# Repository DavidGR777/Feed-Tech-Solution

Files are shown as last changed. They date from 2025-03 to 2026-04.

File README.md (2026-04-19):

# Feed-Tech-Solution
IoT System for Feeding and Growth Monitoring in Cattle.
Project developed as part of the emphasis "IoT Fundamentals and Applications."
The IoT system included the next activities and tasks:

- Implementation of an IoT system using a Raspberry Pi 3 microprocessor.

- Application of RFID, flow, and load sensors.

- Implementation of servomotor actuador, LED RGB and an alert system.

- Delevopment of a project web page using database MySQL and back-end for PHP

- Cloud computing implementation and data performance in a Dashboard using Thingsboard

[Project conception doc](docs/project_conception.pdf)

<p align="center">
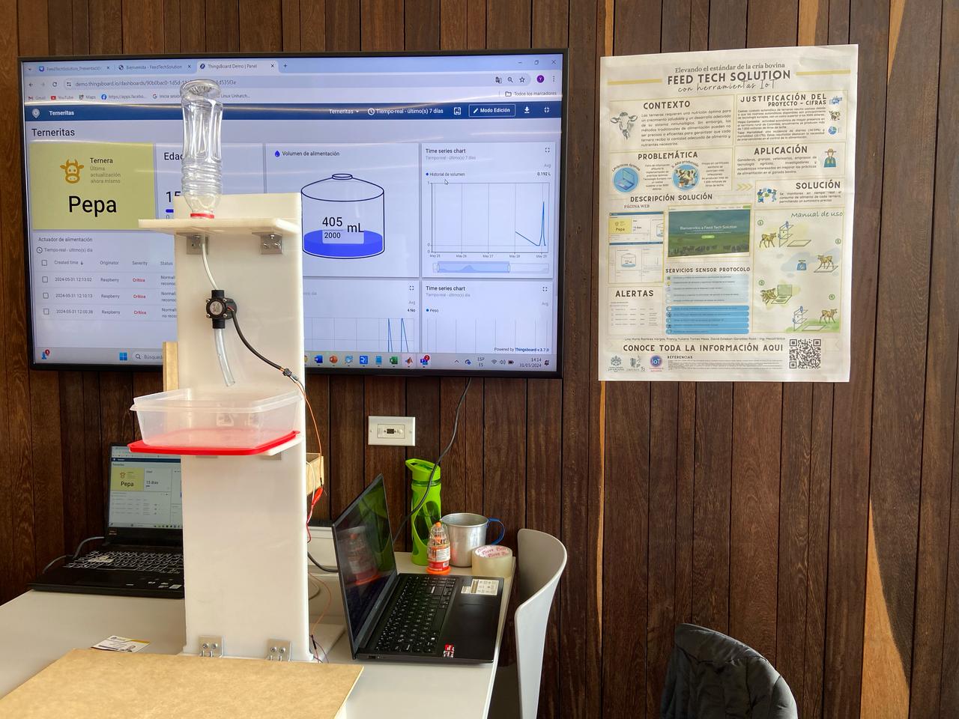
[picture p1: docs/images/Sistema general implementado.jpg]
  
</p>

### Expo-proyectos Javeriana participation certificate  
This project was presented in Expo-proyectos Javeriana and we got the following certificate of participation 
[Certificado](docs/expoproyectos/Certificado_Expoproyectos.pdf)

### 🌐 Active web page  
You can explore the  active project web page here:
🔗 [Feed-Tech-Solution Web](http://feedtechsolution.infinityfreeapp.com/). The Free Web Hosting of the web page is infinityfree. It is able to support back-end with PHP y MySQL

## Project Members

- Lina Ramírez
- Yuliana Torres
- David González

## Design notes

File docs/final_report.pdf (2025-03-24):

PONTIFICIA UNIVERSIDAD JAVERIANA
FACULTAD DE INGENIERIA - DEPARTAMENTO DE ELECTRONICA INTERNET DE LAS COSAS

Entrega Fase 3 – Feed Tech Solution.

Ramírez Vargas, Lina María#1 González Rozo, David Esteban#2 Torres Mesa, Francy Yuliana#3

Ingeniería mecatrónica, Pontificia Universidad Javeriana Bogotá, Colombia

1

lina.ramirezv@javeriana.edu.co 2desteban.gonzalezr@javeriana.edu.co 3 torresmfrancy@javeriana.edu.co

Se realizaron ajustes iniciales en el código para permitir la transmisión de datos a ThingsBoard. El primer cambio se centró en la conexión, que se dividió en dos partes: el host y el token del dispositivo. Inicialmente, el dominio era 10.195.28.12; sin embargo, se observó que este dominio solo era funcional con el internet de la universidad, lo que impedía la conexión con la Raspberry. Por lo tanto, se creó una nueva cuenta en ThingsBoard, a partir de la cual se desarrolló toda la interfaz de usuario.

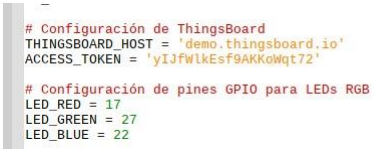
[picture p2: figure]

Además, se incorporó un LED RGB para indicar cuando el sensor RFID RC522 identificaba un tag. Cuando la ternera estaba registrada en la base de datos, el LED mostraba luz verde; en caso contrario, se encendía en rojo. Por lo que no se está utilizando el canal azul del Led.

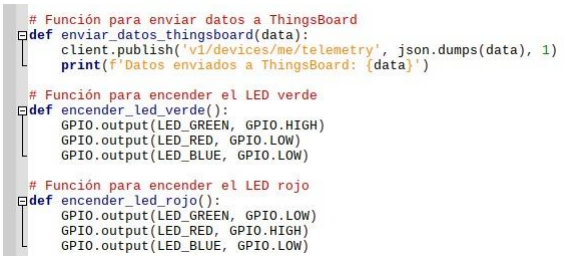
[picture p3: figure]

El actuador utilizado fue un servomotor, encargado de abrir o detener el flujo de alimento para las terneras. Su funcionamiento se divide en dos fases: primero, cuando un tag se acerca al sensor de identificación, el servomotor se activa y gira su palanca 180°, permitiendo el flujo de leche hacia la taza de las terneras a través de una manguera. Dado que la cantidad de alimento está estipulada según la edad de las terneras, una vez que se alcanza el volumen esperado, el servomotor se activa nuevamente, regresando a su posición inicial para detener el flujo.

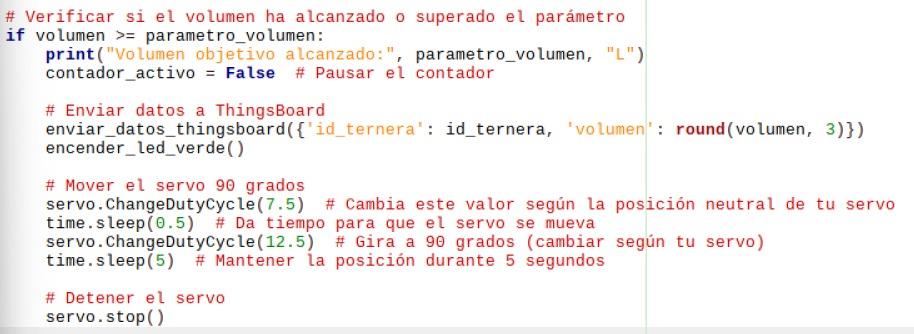
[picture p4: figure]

Para implementar las alertas en el dashboard, se crearon diagramas de flujo en ThingsBoard. En este caso, se configuró una alerta para el sensor de identificación. Esta alerta se activa cuando una ternera se registra más de dos veces al día.

El proceso comenzó con el diseño de un diagrama de flujo que define los criterios y las condiciones necesarias para generar la alerta. Si el sistema detecta que una ternera ha sido registrada más de dos veces en un día, se envía una notificación al panel de control.

Esta alerta es indispensable para asegurar que las terneras no reciban más alimento del que está establecido, manteniendo un control sobre su alimentación.

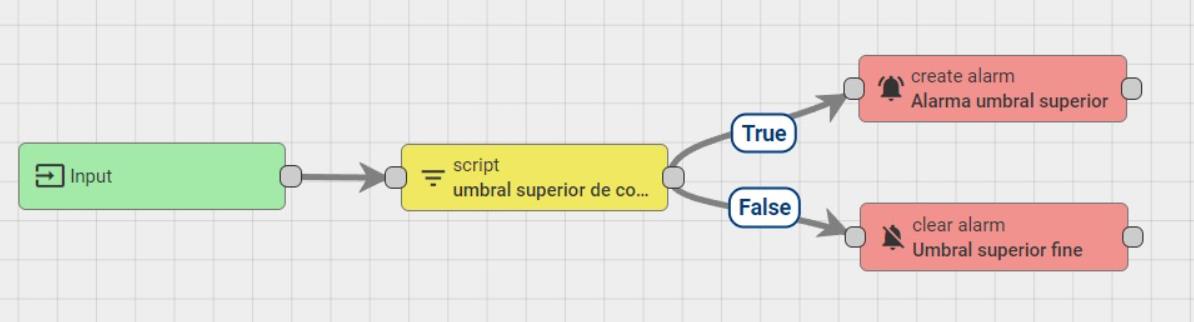
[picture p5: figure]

Otro cambio que se realizó, siguiendo la recomendación del profesor, fue la modificación del sistema de registro por correo electrónico. Ahora es posible registrarse utilizando cualquier dominio, como 'gmail.com', 'javeriana.edu.co', entre otros, lo cual era necesario, ya que anteriormente, el sistema de registro estaba restringido a ‘gmail.com’, lo cual limitaba la accesibilidad para algunos usuarios.

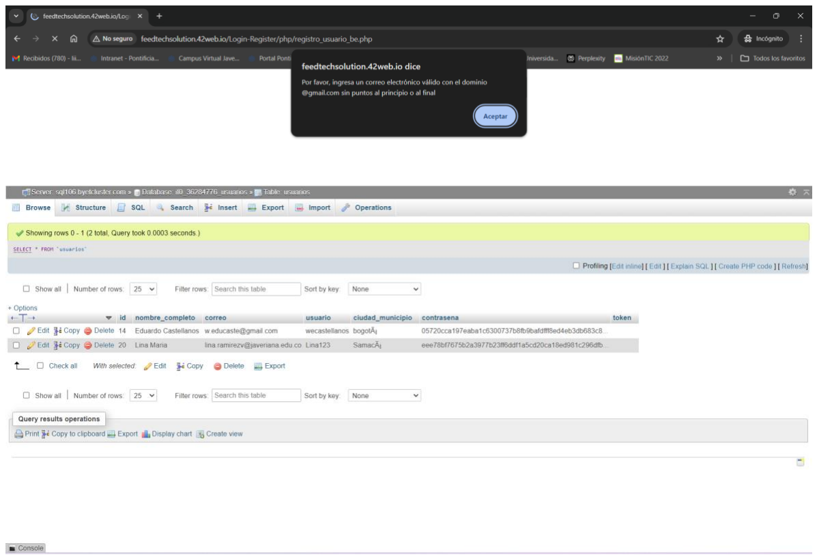
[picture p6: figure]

Además, se intentó implementar la función de 'Olvidó su contraseña'. Sin embargo, a pesar de numerosos intentos, no fue posible debido a las limitaciones del hosting gratuito, que restringe ciertas opciones, incluida la recuperación de contraseñas.

Se intentó resolver este problema utilizando el protocolo de comunicación SMTP para enviar correos electrónicos de recuperación de contraseña. Sin embargo, las restricciones del hosting gratuito impidieron completar esta configuración. Por lo tanto, esta funcionalidad no pudo ser implementada en la plataforma actual.

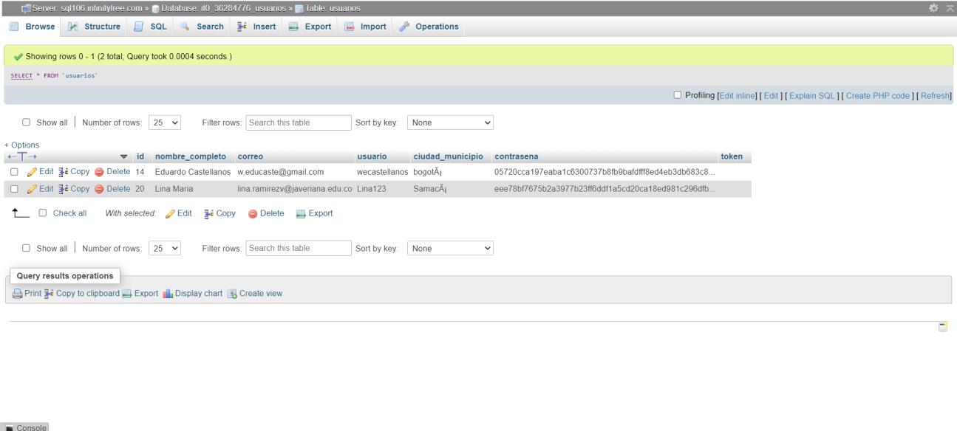
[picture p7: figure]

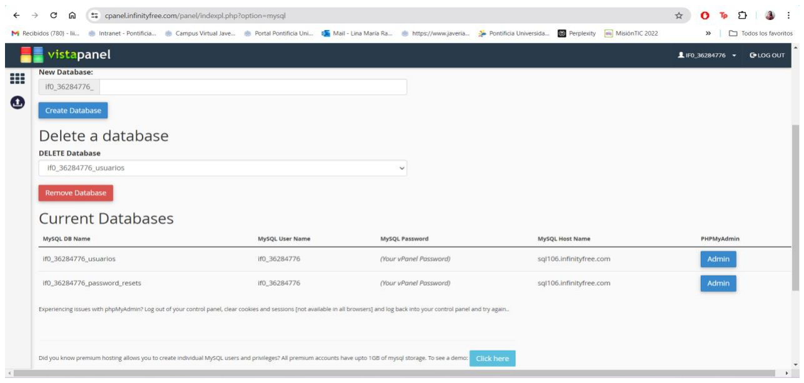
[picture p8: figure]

Para la implementación del dashboard, se conectó el código unificado de los sensores utilizando el dominio y el token del dispositivo, como se mencionó anteriormente. Las primeras pruebas se realizaron con el sensor de identificación, utilizando la información almacenada en la base de datos local de cada tag, que incluía la edad y el ID único de cada ternera.

Posteriormente, se realizó una prueba enviando los datos del sensor de flujo. En este caso, se configuró una alerta para detectar si se recibe más leche de la esperada según la tabla de alimentación disponible en la página web del proyecto. Esta alerta indica un posible fallo en el actuador encargado de detener el flujo de la leche.

Además, se creó un gráfico que muestra el peso inicial de cada ternera y su evolución a lo largo del tiempo. Este gráfico permite monitorear el crecimiento de las terneras y ajustar su alimentación en consecuencia, asegurando un desarrollo saludable y adecuado para cada una.

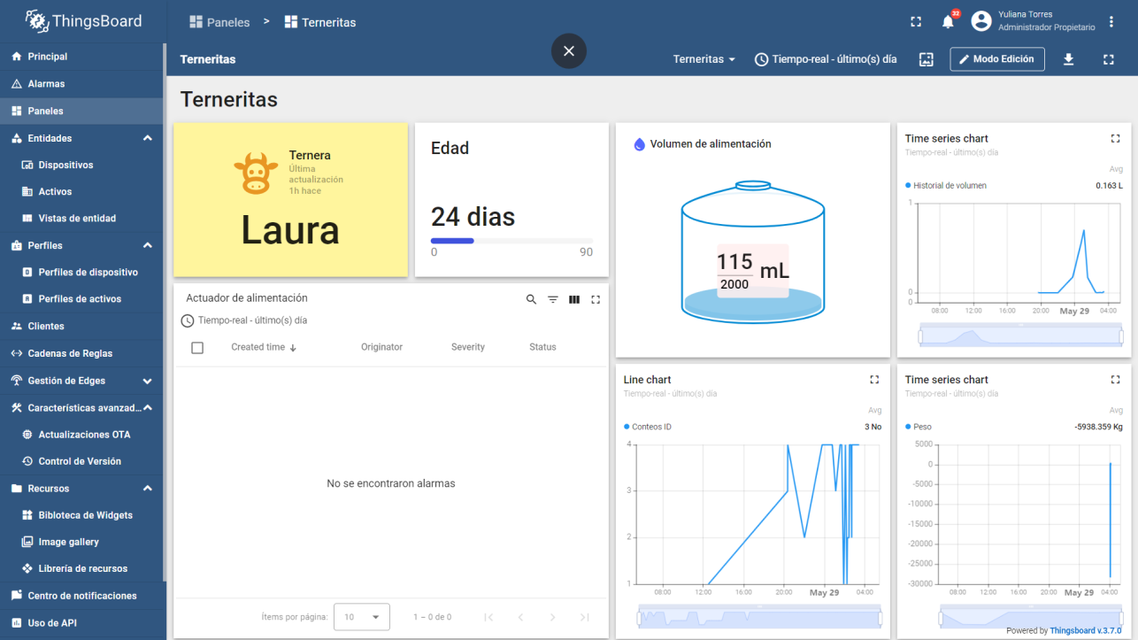
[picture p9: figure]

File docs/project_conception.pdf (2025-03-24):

# Proyecto

# SOLUCIÓN

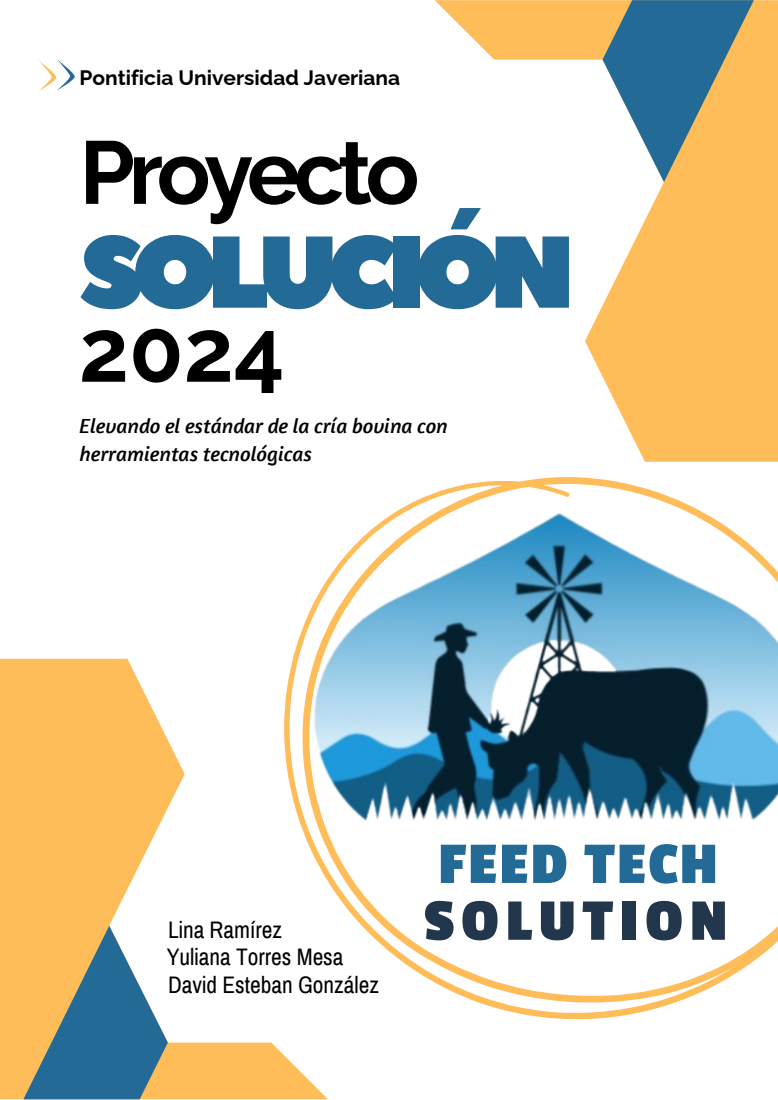
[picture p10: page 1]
FEED TECH SOLUTION

Pontificia Universidad Javeriana

Elevando el estándar de la cría bovina con
herramientas tecnológicas

Lina Ramírez
Yuliana Torres Mesa
David Esteban González

# Área de aplicación

# Descripción del problema

El proyecto Feed Tech Solution tiene como área de aplicación principal la industria ganadera, específicamente en la cría y cuidado
de terneras durante los primeros meses de vida.

Este sistema innovador de alimentación está diseñado para su utilización por ganaderos, productores de leche, granjas, veterinarios, empresas de tecnología agrícola, así como investigadores y académicos interesados en mejorar las prácticas de alimentación y nutrición en el ganado bovino.

## Justificación:

El problema que Feed Tech Solution busca resolver radica en la dificultad que enfrentan los ganaderos para proporcionar una alimentación adecuada y equilibrada a las terneras durante los primeros meses de vida en las fincas ganaderas. Durante este período, las terneras requieren una nutrición óptima para un crecimiento saludable y un desarrollo adecuado de su sistema inmunológico. Sin embargo, los métodos tradicionales de alimentación pueden no ser suficientemente preciso o eficientes para garantizar que cada ternera reciba la cantidad adecuada de alimento y los nutrientes necesarios. Esto puede conducir a problemas de crecimiento deficiente, enfermedades, infecciones que pueden causar la muerte y/o una menor productividad en el ganado a largo plazo. Por lo tanto, el desafío radica en encontrar una solución que permita a los ganaderos monitorear y controlar de manera efectiva la alimentación de las terneras, asegurando así su salud y bienestar desde una etapa temprana.

En Colombia la disponibilidad de información sobre ganadería, especialmente en lo que respecta al crecimiento y desarrollo de las terneras, es limitada, a pesar de la importancia del sector para la economía nacional. Esta falta de información podría dificultar la implementación de prácticas óptimas en la cría de ganado bovino. Además, el cuidado automático de terneras resulta costoso debido a que las nodrizas automáticas disponibles son principalmente de tecnología europea, con un costo superior a los 3000 dólares por unidad. Esta inversión representa un desafío para los ganaderos, especialmente los de pequeña escala o con recursos limitados.

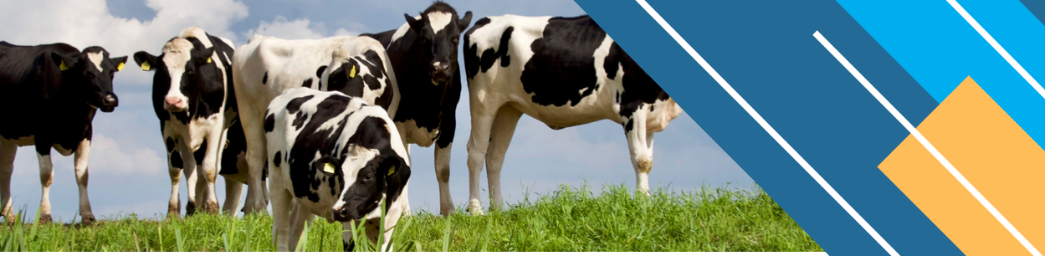
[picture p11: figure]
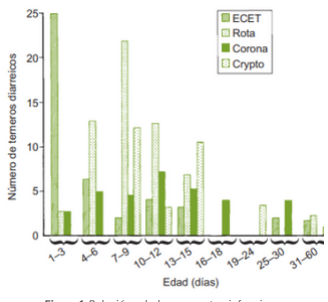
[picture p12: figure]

# Descripción de la solución

## Cifras y estadísticas:

La ganadería es la actividad económica de mayor presencia en el territorio rural de Colombia, anualmente se producen más de 7.000 millones de litros de leche, siendo la ganadería 3 veces más que el sector cafetero y 5,2 veces más que el sector bananero. [1]

En cuanto a la alimentación, según un estudio en terneros
Holstein de 2 a 65 días, reveló una alta incidencia de
diarrea (48.59%) y mortalidad (20.17%). Estos resultados
destacan la necesidad de intervenciones en el control de la alimentación para reducir estos problemas. [2]

En otro estudio realizado en una de las fincas ganaderas de Antioquia sin un plan sanitario certificado, se observa que en las primeras semanas se es más susceptible a contraer infecciones como se ve en la gráfica. [3]

Figura 1. Relación edad con agentes infecciosos

La solución propuesta para la automatización de la alimentación de terneras en sus primeros días de vida integra tecnología de Internet de las Cosas (IoT) para ofrecer un nuevo enfoque.
A través de sensores y dispositivos conectados, se monitorea en tiempo real el consumo de alimento de cada ternera, permitiendo un suministro preciso y personalizado según las necesidades individuales de cada animal. Los datos recopilados son analizados mediante algoritmos programados, lo que permite ajustar automáticamente la cantidad y frecuencia de alimentación para optimizar el crecimiento y la salud de las terneras.

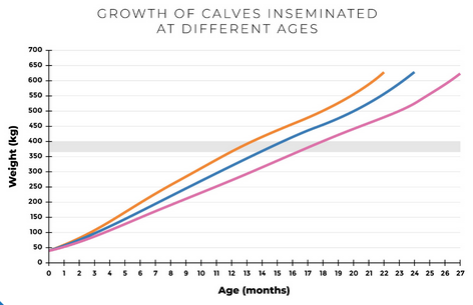
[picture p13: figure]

Además, la plataforma IoT proporciona alertas en tiempo real sobre cualquier anomalía o problema en el proceso de alimentación, permitiendo una respuesta rápida y eficaz por parte del personal encargado.

Figura 2. Crecimiento esperado para terneros.

En el siguiente diagrama se proporciona uan representación de los diferentes componentes y como interactúan entre sí.

## Diagrama de bloques:

El fenómeno del crecimiento compensatorio no se aplica luego, así que los primeros seis meses de vida son importantes. Un crecimiento de unos 800g/día es óptimo para la ternera (ver figura 2). Las terneras mas pesadas a los 6 meses (>200kg) son las que presentan mejores resultados de fertilidad, longevidad y producción de leche. [4]

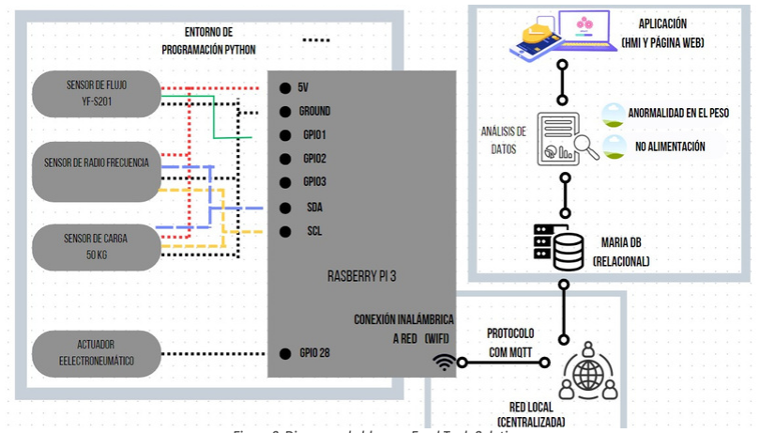
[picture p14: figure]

Este diagrama ofrece una visión general del funcionamiento del sistema, proporcionando una guía visual para comprender su operación de manera intuitiva.

## Diagrama de alto nivel:

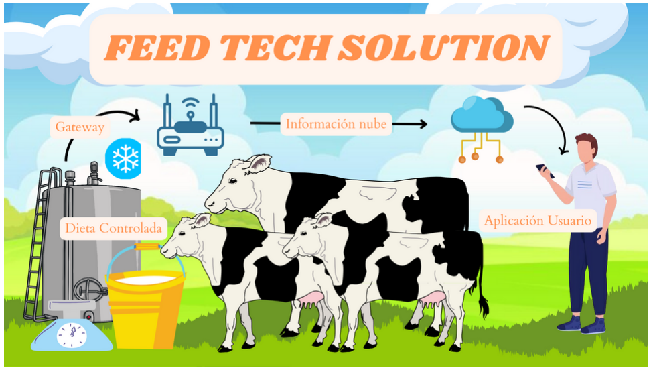
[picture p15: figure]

Figura 4. Diagrama de alto nivel Feed Tech Solution.

Figura 3. Diagrama de bloques Feed Tech Solution.

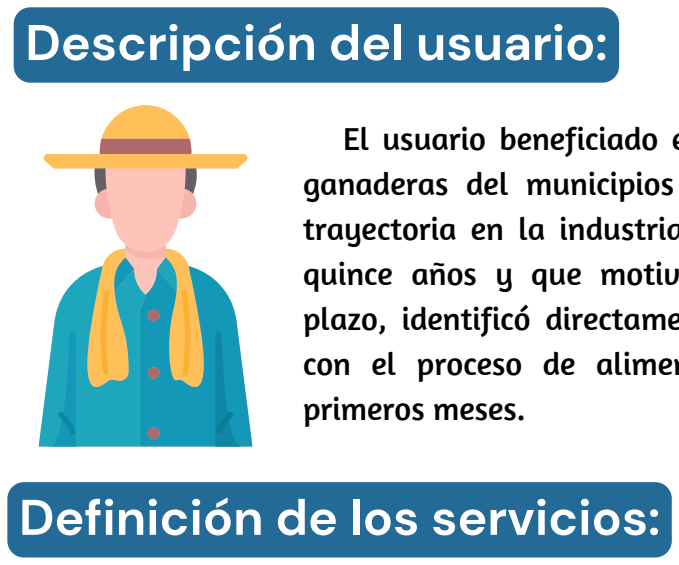
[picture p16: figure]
primeros meses.; Descripción del usuario:; Definición de los servicios:

El usuario beneficiado es el dueño de una de las fincas ganaderas del municipios de Samacá - Boyacá, con una trayectoria en la industria ganadera de aproximadamente quince años y que motivado por el crecimiento a largo plazo, identificó directamente la problemática relacionada con el proceso de alimentación de sus terneras en los

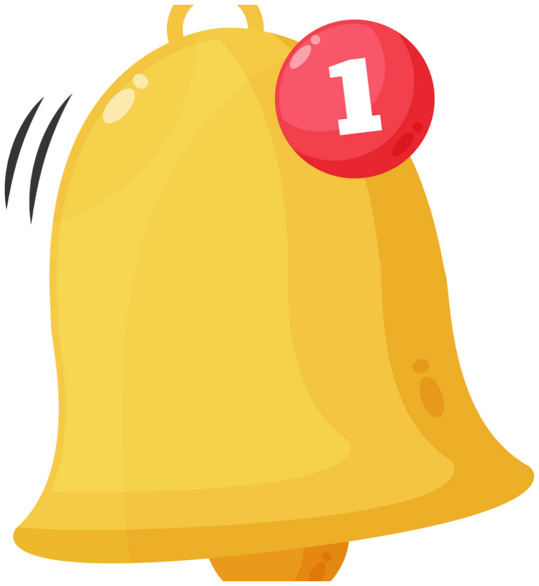
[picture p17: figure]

Dentro de la configuración de los sensores es necesario tener en cuenta y establecer un parámetro generalizado de la cantidad de alimento para cada una de las terneras. En la figura 4 se muestra la cantidad según el peso del animal. Además, se considera una temperatura que en lo posible debe ser la misma siempre y a la misma hora.
La higiene es tambien fundamental por lo que este al ser un sistema cerrado minimiza la intervención externa y por tanto la posibilidad de infecciones.

## Descripciones generales:

La implementación de tecnología permite el control y monitoreo eficiente de las nodrizas, proporcionando la cantidad precisa y control de las terneras, replicando el cuidado e higiene para evitar las infecciones. Los servicios son: 1.Implementación del sistema: configuración de los sensores y actuadores 2.Desarrollo de software: Plataforma personalizada con interfaz de usuario

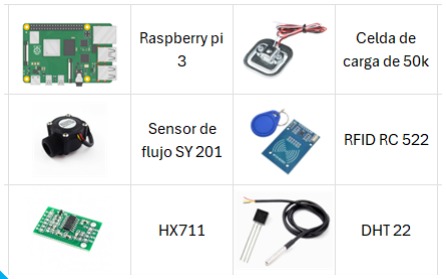
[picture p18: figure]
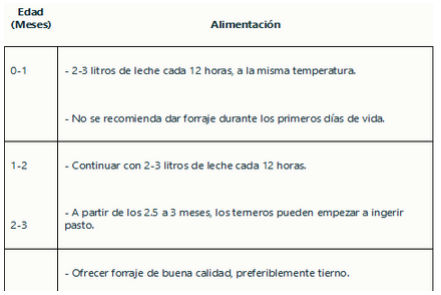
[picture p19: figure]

Figura 3. Implementos usados en el proyecto. | Figura 4. Alimentación de las terneras según la edad.
- Raspberry pi 3: microcontrolador base - Sensor sy 201: flujo de leche para cada ternera - Celda de carga de 50k: validar el peso de la ternera a diario. -DSB 18b20: sensor de monitoreo de temperatura de la leche - RFID RC 522: sensor de identificación
- HX 711: es el módulo de conversor analógico - digital para la celda de carga.

En la interfaz gráfica de usuario se espera que al ser de fácil manejo, los datos y el uso para el ganadero sea casi intuitivo. En primer lugar se presenta información de caracterización de la ternera, con datos adicionales que se deseen adicionar, seguido de esto, la edad y el número de identificación. La gráfica de crecimiento muestra si se está dando de manera correcta según los parámetros ya comentados y un botón de alerta por si no funciona bien el sistema. Lo siguiente son las gráficas de peso, una personal y la otra respecto a un promedio y de igual manera la cantidad de alimento suministrado. La información de siguiente fase corresponde al porcentaje de avance durante los tres meses, una vez cumplida esta edad, sale de este proceso de alimentación, pues ahora debe comer concentrado.

# Interfaz gráfica de usuario

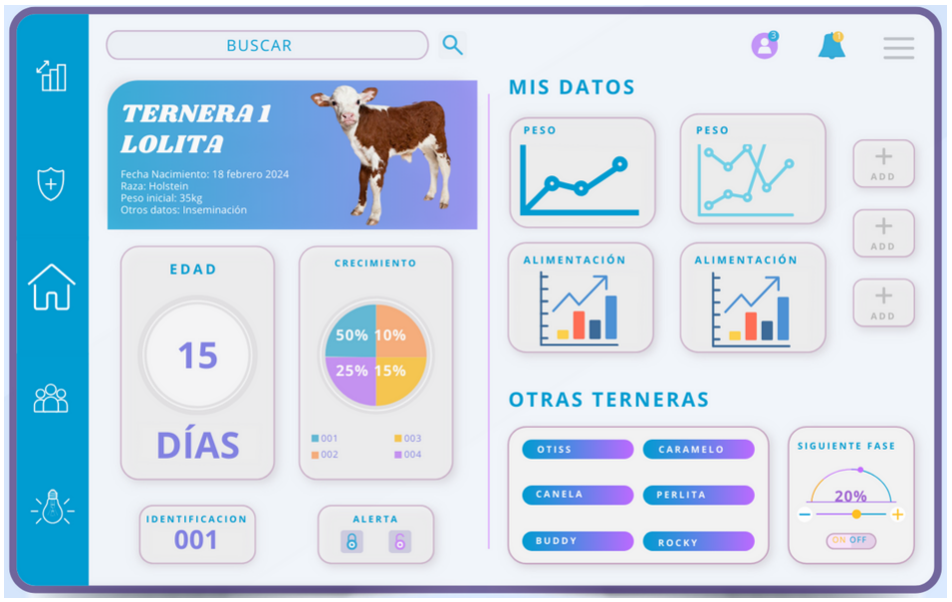
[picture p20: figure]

Figura 5. Interfaz gráfica de usuario.

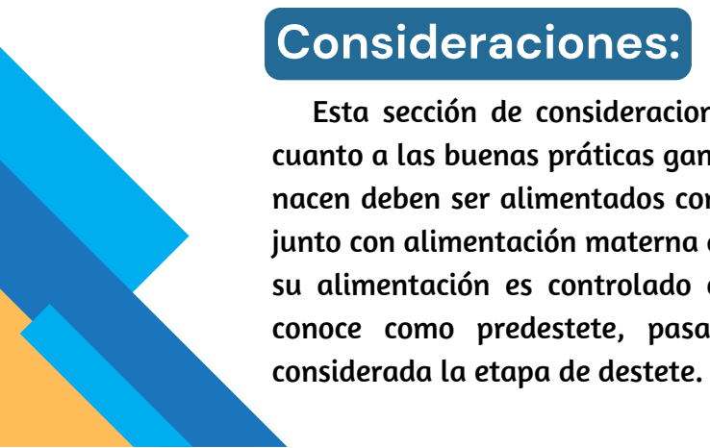
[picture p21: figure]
considerada la etapa de destete.; Consideraciones:

Esta sección de consideraciones tiene en cuenta otros datos adicionales en cuanto a las buenas práticas ganaderas y de cuidado de los terneros. Tan pronto nacen deben ser alimentados con calostros y dentro de estas primeras 24 horas junto con alimentación materna debe adquirir 10 kilos de peso. A partir del día 2, su alimentación es controlado con Feed Tech Solution y a esta estapa se le conoce como predestete, pasados tres meses sale de este proceso y es

# Antecedentes

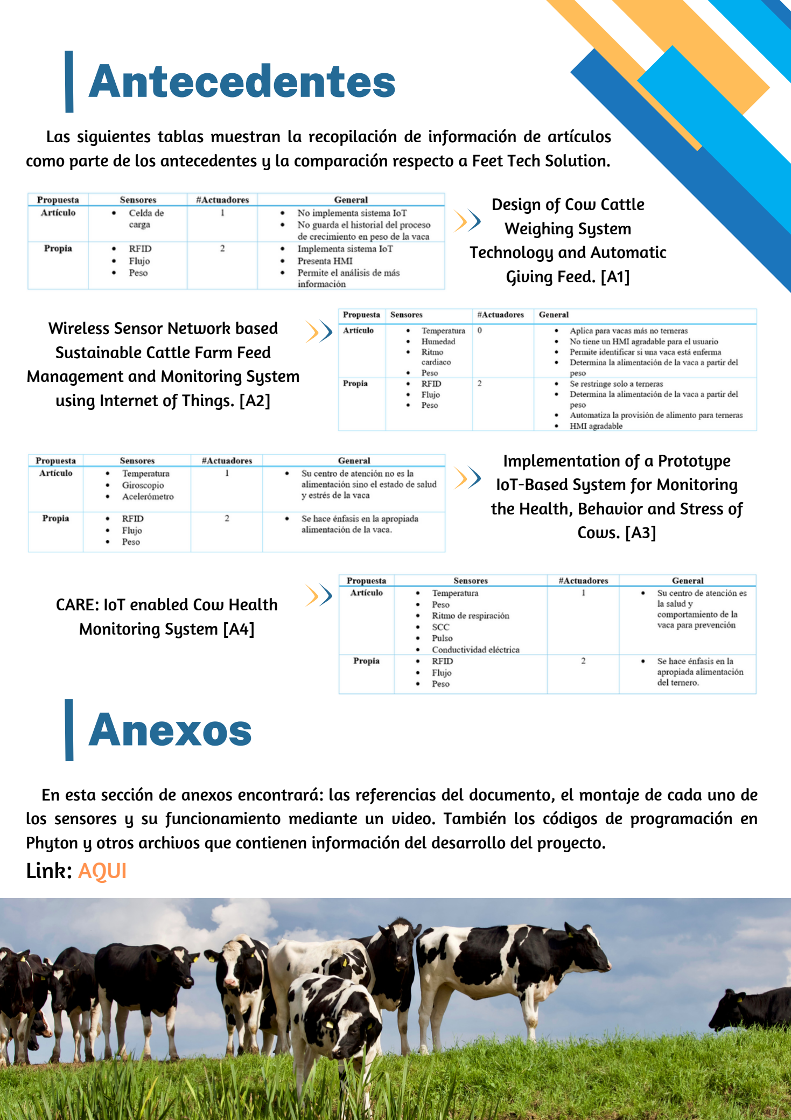
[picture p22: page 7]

Las siguientes tablas muestran la recopilación de información de artículos como parte de los antecedentes y la comparación respecto a Feet Tech Solution.

# Anexos

En esta sección de anexos encontrará: las referencias del documento, el montaje de cada uno de los sensores y su funcionamiento mediante un video. También los códigos de programación en Phyton y otros archivos que contienen información del desarrollo del proyecto.
Link: AQUI (https://livejaverianaedu-my.sharepoint.com/:f:/g/personal/lina_ramirezv_javeriana_edu_co/EnmLIeDjfP5OvYbf9VVIlEoBRGlZDpHc1Rl4A16tMxb4Pg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)

Design of Cow Cattle
Weighing System
Technology and Automatic
Giving Feed. [A1]

Wireless Sensor Network based Sustainable Cattle Farm Feed Management and Monitoring System using Internet of Things. [A2]

Implementation of a Prototype IoT-Based System for Monitoring the Health, Behavior and Stress of Cows. [A3]

CARE: IoT enabled Cow Health Monitoring System [A4]

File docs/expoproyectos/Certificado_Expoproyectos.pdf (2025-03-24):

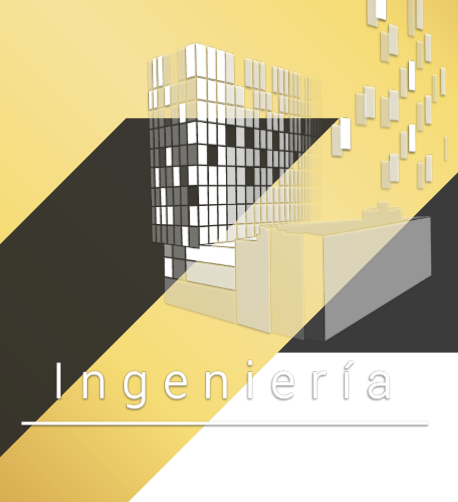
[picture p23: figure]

# Certificado de Participación

EN RECONOCIMIENTO AL PROYECTO Feed Tech Solution

Lina María Ramírez Vargas, Francy Yuliana Torres Mesa, David Esteban González Rozo

POR SU COMPROMISO Y PARTICIPACIÓN EXPO PROYECTOS 2410
PONTIFICIA UNIVERSIDAD JAVERIANA

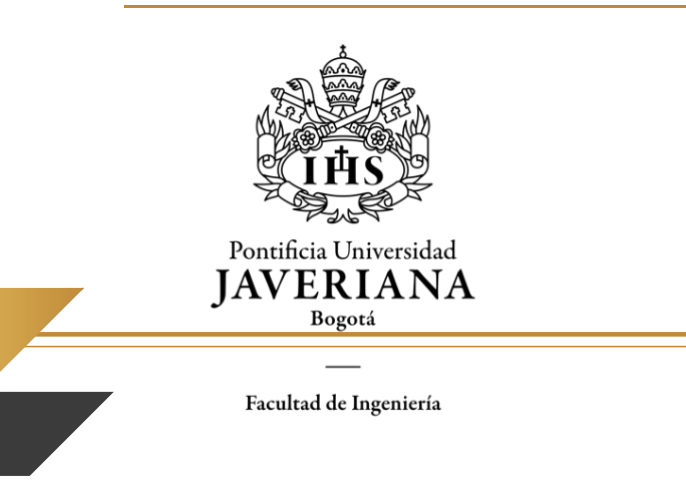
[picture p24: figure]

31 Mayo 2024 | Director de Carrera

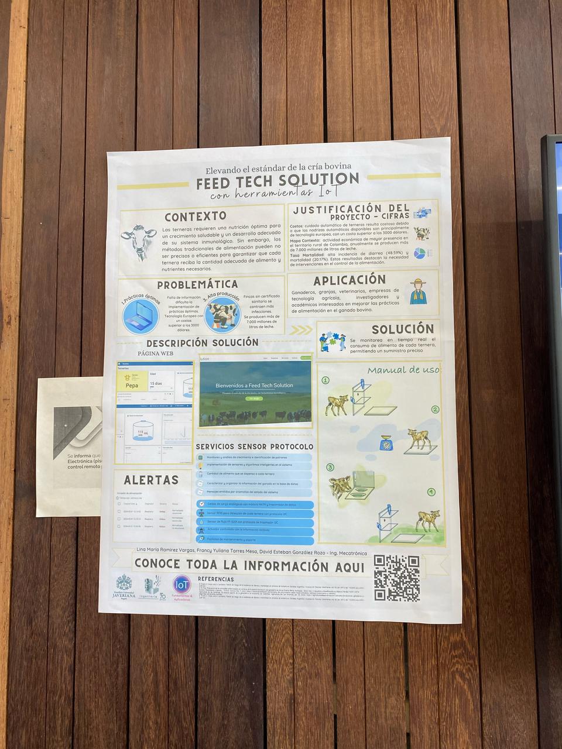
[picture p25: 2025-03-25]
docs/images/poster expo.jpg

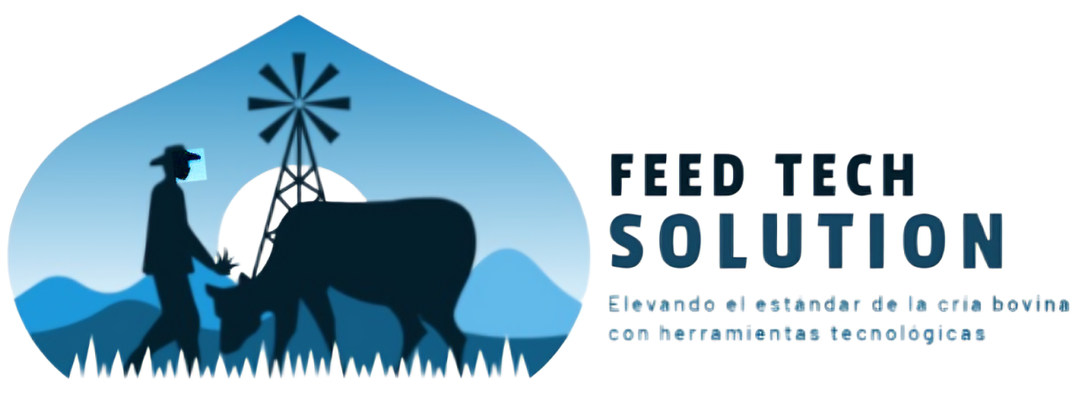
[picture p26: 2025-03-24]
web-page/img/Diseño sin título.png

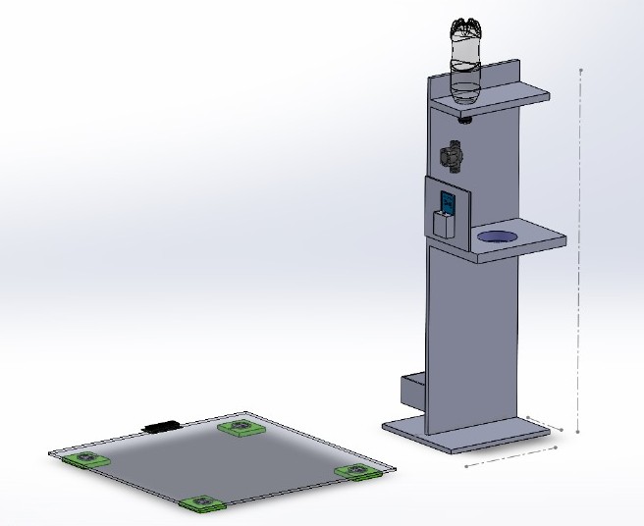
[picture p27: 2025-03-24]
cad-design/Diseño CAD.jpg

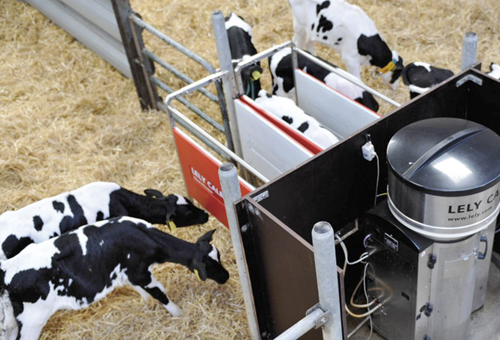
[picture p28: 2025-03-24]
web-page/img/imagen9.jpg

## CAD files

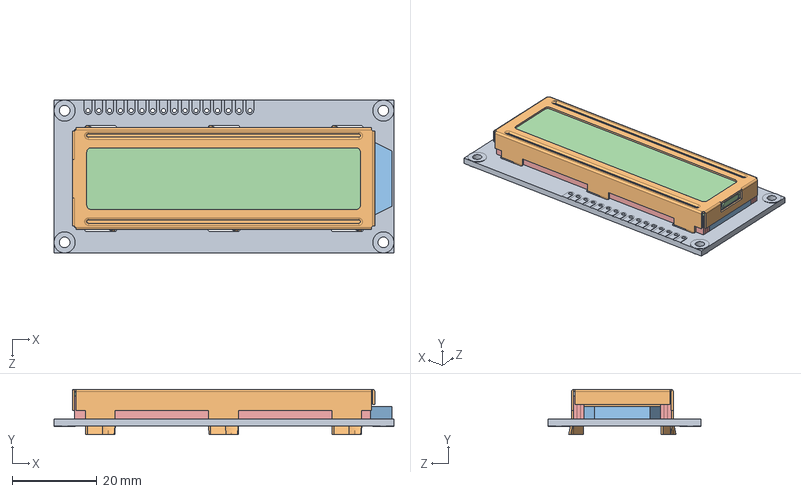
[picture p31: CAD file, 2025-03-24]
cad-design/LCD/DFRobot_1602_LCD.SLDASM
80.0 x 10.6 x 36.0 mm
LCD_PCB
metal_casing
LCDbacklight
LCD
conductors x 2

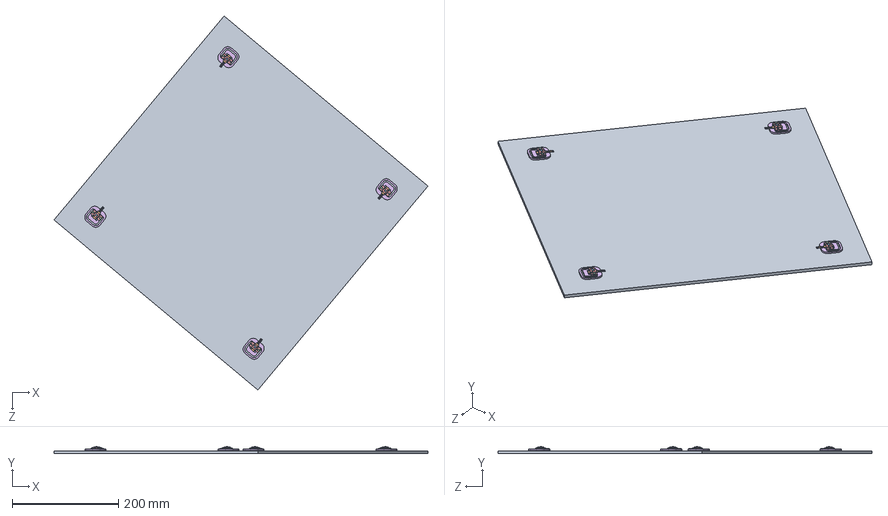
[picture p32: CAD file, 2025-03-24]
cad-design/Celda de carga/Balanza.SLDASM
704.2 x 13.8 x 704.2 mm
BASE, 50 kg Load Cell Resistance Strain Half Bridge Sensor x 4
FLANGED TOP, 50 kg Load Cell Resistance Strain Half Bridge Sensor x 4
SIDE RIVET, 50 kg Load Cell Resistance Strain Half Bridge Sensor x 5
MIDDLE RIVET, 50 kg Load Cell Resistance Strain Half Bridge Sensor x 4
WIRED CONNECTION, 50 kg Load Cell Resistance Strain Half Bridge Sensor x 4
Base sup celda

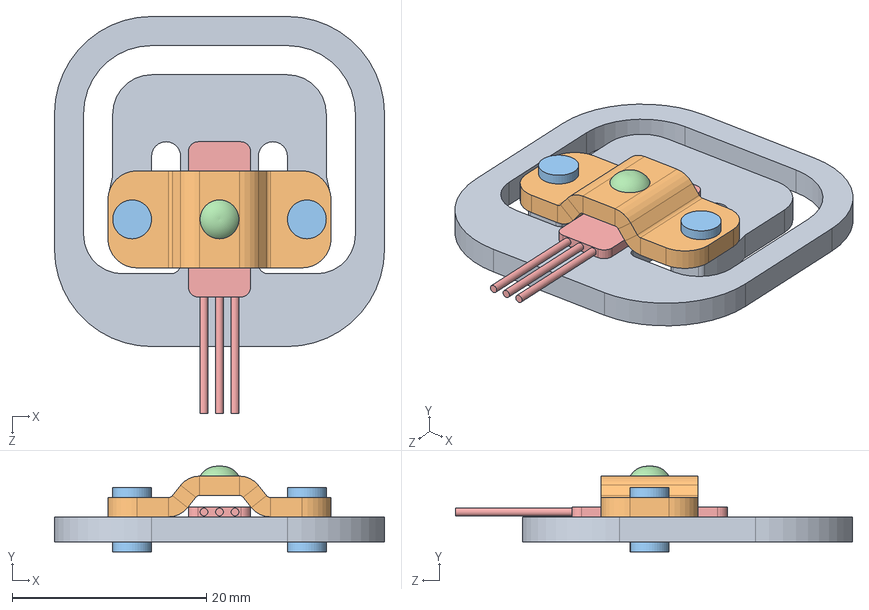
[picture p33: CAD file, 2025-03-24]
cad-design/Celda de carga/50 kg Load Cell Resistance Strain Half Bridge Sensor.SLDASM
34.0 x 8.82 x 40.9 mm
BASE, 50 kg Load Cell Resistance Strain Half Bridge Sensor
FLANGED TOP, 50 kg Load Cell Resistance Strain Half Bridge Sensor
SIDE RIVET, 50 kg Load Cell Resistance Strain Half Bridge Sensor x 2
MIDDLE RIVET, 50 kg Load Cell Resistance Strain Half Bridge Sensor
WIRED CONNECTION, 50 kg Load Cell Resistance Strain Half Bridge Sensor

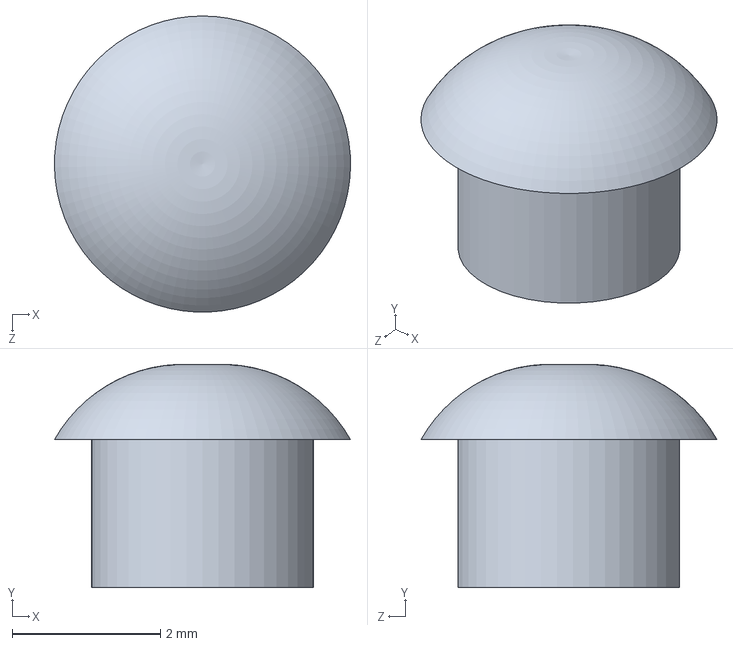
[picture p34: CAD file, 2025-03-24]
cad-design/Celda de carga/MIDDLE RIVET, 50 kg Load Cell Resistance Strain Half Bridge Sensor.SLDPRT
4.00 x 3.02 x 4.00 mm

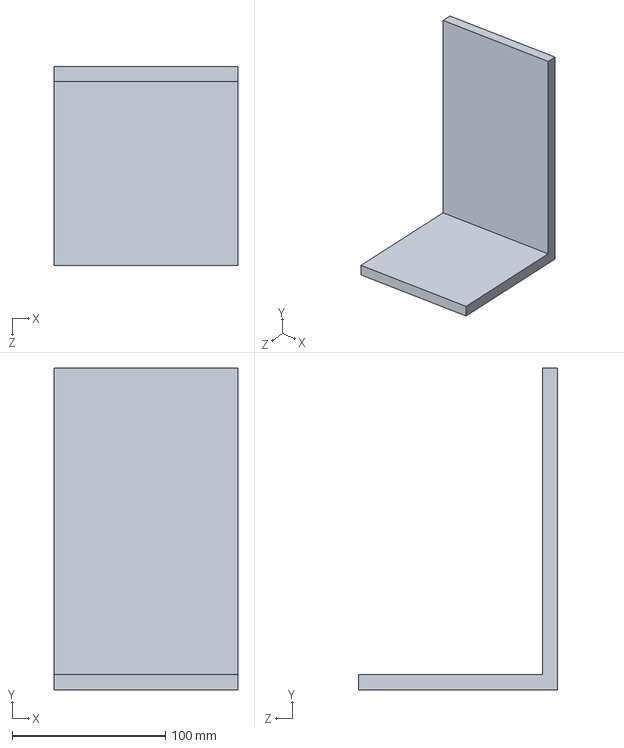
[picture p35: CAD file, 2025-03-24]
cad-design/estructura.SLDPRT
120.0 x 210.0 x 130.0 mm

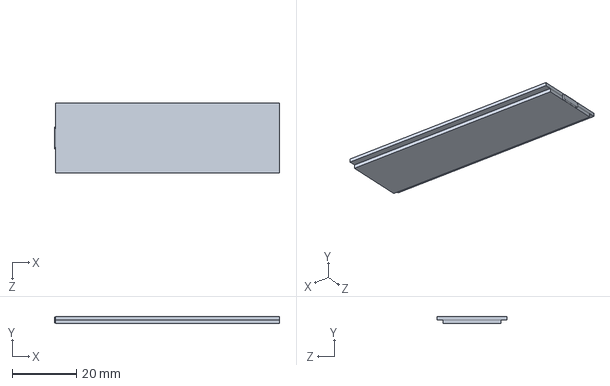
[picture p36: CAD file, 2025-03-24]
cad-design/LCD/LCD.SLDPRT
70.3 x 2.10 x 22.0 mm

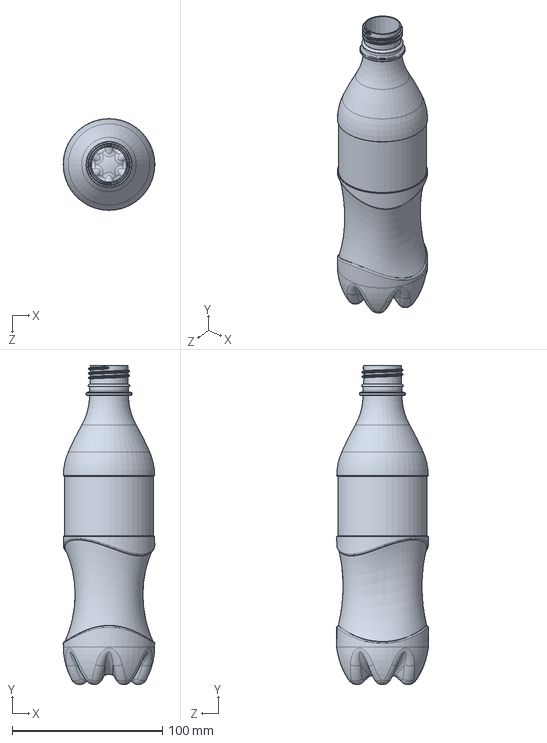
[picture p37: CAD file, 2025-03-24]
cad-design/Botella cocacola.SLDPRT
61.0 x 212.5 x 61.0 mm

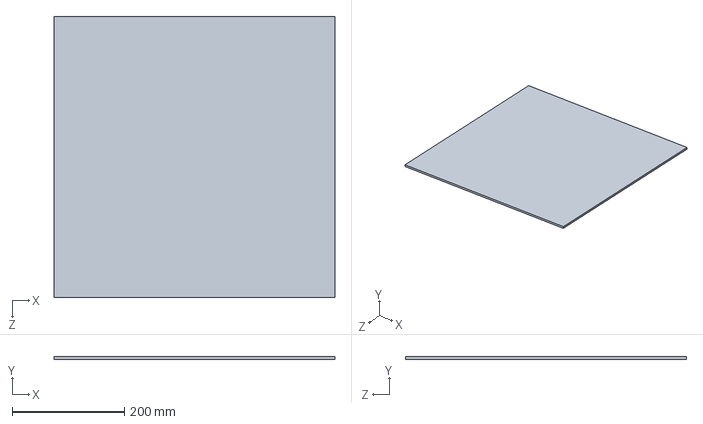
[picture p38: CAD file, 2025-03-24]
cad-design/Celda de carga/Base sup celda.SLDPRT
500.0 x 5.00 x 500.0 mm

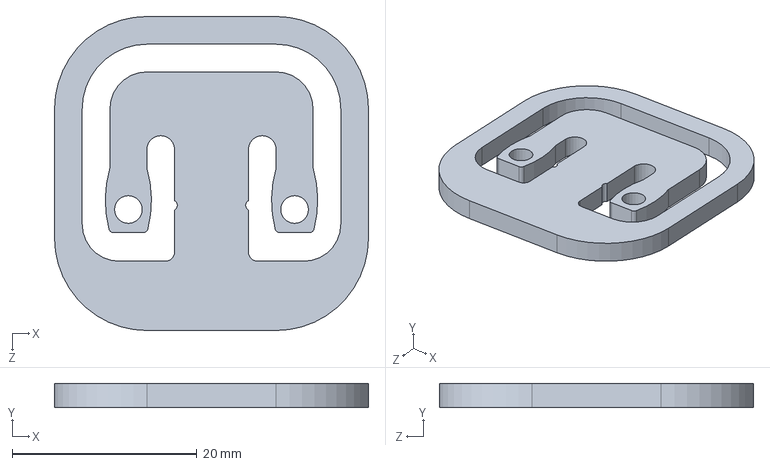
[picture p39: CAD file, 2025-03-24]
cad-design/Celda de carga/BASE, 50 kg Load Cell Resistance Strain Half Bridge Sensor.SLDPRT
34.0 x 2.60 x 34.0 mm

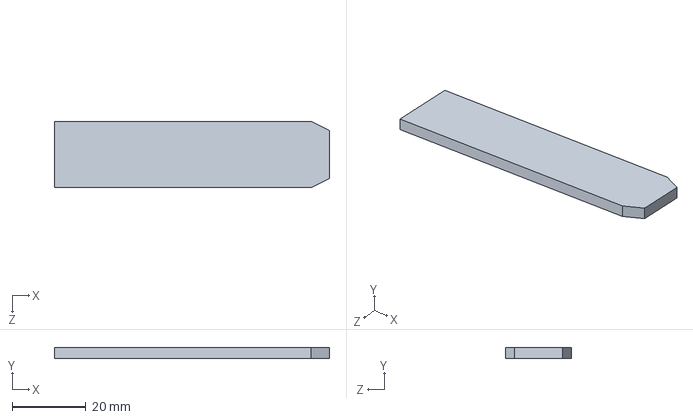
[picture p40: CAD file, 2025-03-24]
cad-design/LCD/LCDbacklight.SLDPRT
74.7 x 3.00 x 18.0 mm

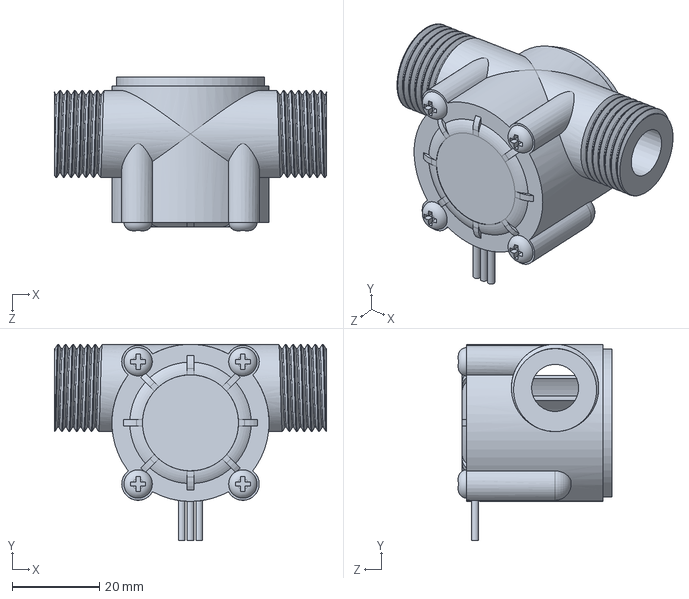
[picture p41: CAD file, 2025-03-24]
cad-design/Water Flow Sensor YF-S201.SLDPRT
62.3 x 45.0 x 35.2 mm

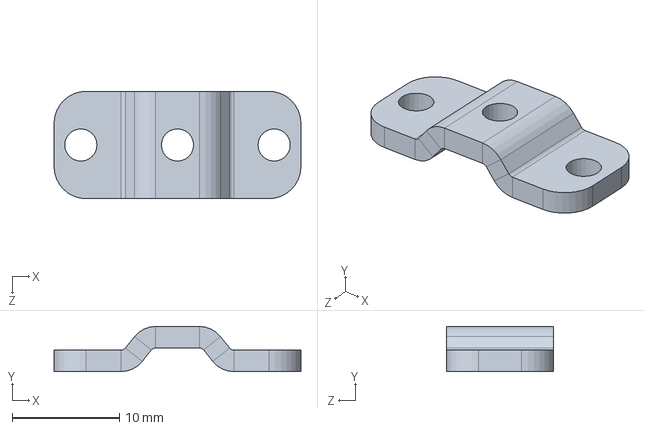
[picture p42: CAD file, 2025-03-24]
cad-design/Celda de carga/FLANGED TOP, 50 kg Load Cell Resistance Strain Half Bridge Sensor.SLDPRT
23.0 x 4.20 x 10.0 mm

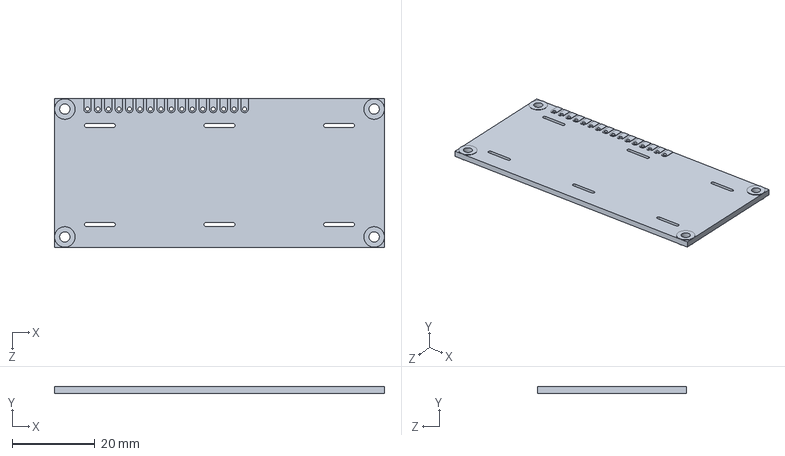
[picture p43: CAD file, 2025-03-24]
cad-design/LCD/LCD_PCB.SLDPRT
80.0 x 1.80 x 36.0 mm

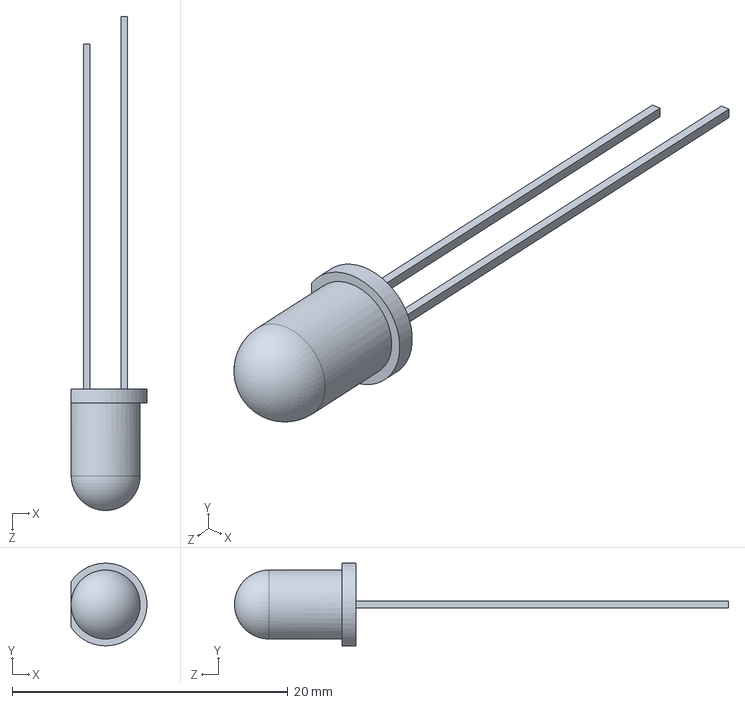
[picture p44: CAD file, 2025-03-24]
cad-design/LED 5mm.SLDPRT
5.49 x 6.00 x 35.8 mm

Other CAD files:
cad-design/Celda de carga/SIDE RIVET, 50 kg Load Cell Resistance Strain Half Bridge Sensor.SLDPRT
cad-design/LCD/metal_casing.SLDPRT
cad-design/Soporte RFID.SLDPRT
cad-design/Celda de carga/WIRED CONNECTION, 50 kg Load Cell Resistance Strain Half Bridge Sensor.SLDPRT
cad-design/Celda de carga/Base inf celda.SLDPRT
cad-design/LCD/conductors.SLDPRT
cad-design/RFID-RC522 simple.SLDPRT

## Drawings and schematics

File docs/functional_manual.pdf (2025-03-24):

·

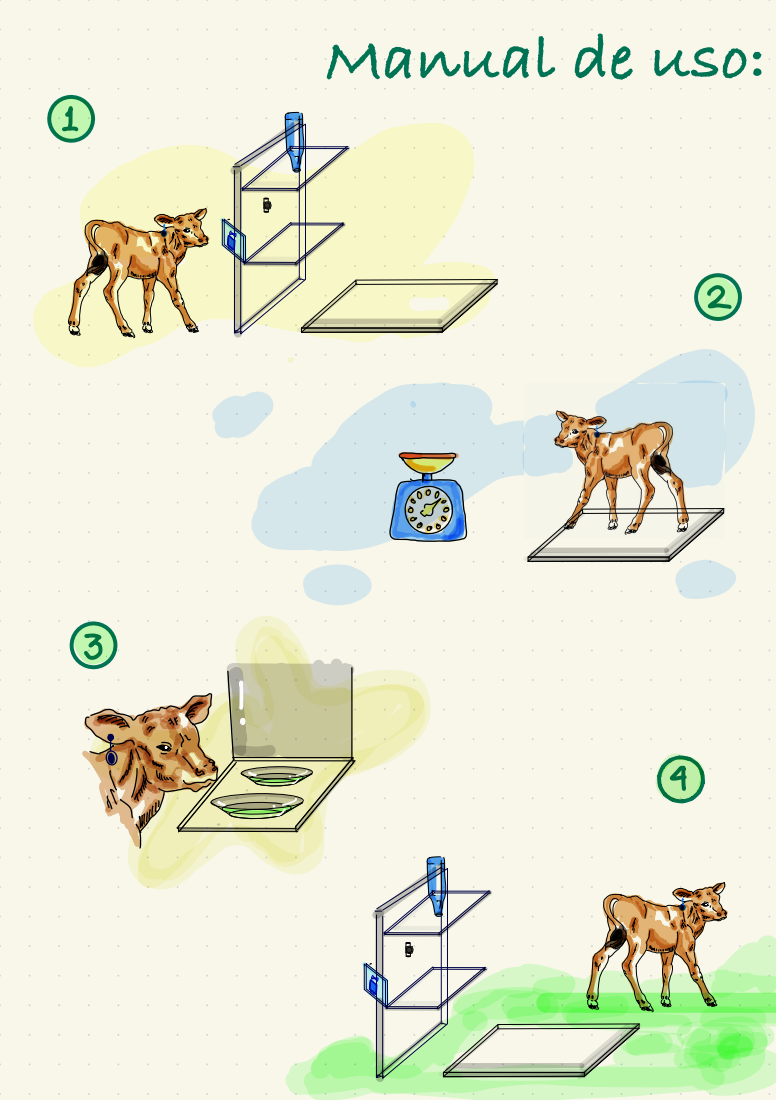
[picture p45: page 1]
/Eim's11/

Manual de uso:

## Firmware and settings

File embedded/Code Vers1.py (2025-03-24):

import RPi.GPIO as GPIO
from pirc522 import RFID
import sqlite3
import requests
from datetime import datetime

# Nombre de la base de datos SQLite
db_name = 'vacas.db'

# Inicialización del lector RFID
GPIO.setmode(GPIO.BOARD)
GPIO.setwarnings(False)
rc522 = RFID()

# Configuración de ThingSpeak
thingspeak_api_key = 'J9V3Q9CKR3FH5ZRP'
thingspeak_url = f'https://api.thingspeak.com/update?api_key={thingspeak_api_key}'

# Función para leer el UID de la tarjeta RFID
def leer_tag():
    try:
        print('Acercar una tarjeta RFID...')
        rc522.wait_for_tag()
        error, _ = rc522.request()
        if not error:
            error, uid = rc522.anticoll()
            if not error:
                uid_str = ''.join(map(str, uid))
                print(f'Tarjeta RFID detectada. UID: {uid_str}')
                return uid_str
        return None
    except KeyboardInterrupt:
        GPIO.cleanup()
        raise

# Función para crear la tabla de vacas si no existe
def crear_tabla_vacas():
    conn = sqlite3.connect(db_name)
    c = conn.cursor()
    c.execute('''CREATE TABLE IF NOT EXISTS vacas (
                    uid TEXT PRIMARY KEY,
                    nombre TEXT,
                    edad INTEGER,
                    peso REAL,
                    id_ternera INTEGER
                )''')
    conn.commit()
    conn.close()

# Función para guardar datos de una vaca en la base de datos
def guardar_datos(uid, nombre, edad, peso, id_ternera):
    conn = sqlite3.connect(db_name)
    c = conn.cursor()
    try:
        c.execute("INSERT INTO vacas (uid, nombre, edad, peso, id_ternera) VALUES (?, ?, ?, ?, ?)",
                  (uid, nombre, edad, peso, id_ternera))
        conn.commit()
        print(f"Datos para la vaca con UID {uid} guardados correctamente en la base de datos.")

        # Enviar datos actualizados a ThingSpeak
        enviar_a_thingspeak_nuevo(uid, nombre)  # Enviar el valor de 1 para contar una nueva vaca
        enviar_a_thingspeak_edad(uid, nombre, edad)  # Enviar la edad al campo field2 de ThingSpeak
        
    except sqlite3.Error as e:
        print("Error al guardar los datos:", e)
    finally:
        conn.close()

# Función para enviar datos actualizados a ThingSpeak
def enviar_a_thingspeak_nuevo(uid, nombre):
    try:
        payload = {'api_key': thingspeak_api_key, 'field1': 1}  # Enviar siempre 1 para contar una nueva vaca
        response = requests.post(thingspeak_url, params=payload)
        
        if response.status_code == 200:
            print(f'Conteo de vacas actualizado en ThingSpeak para la vaca {nombre}.')
        else:
            print(f'Error al actualizar el conteo de vacas en ThingSpeak. Código de estado: {response.status_code}')
    
    except Exception as e:
        print(f'Error en la solicitud HTTP: {e}')


def enviar_a_thingspeak_edad(uid, nombre, edad):
    try:
        print(f'Enviando edad ({edad}) de la vaca {nombre} ({uid}) a ThingSpeak...')
        payload = {'api_key': thingspeak_api_key, 'field2': edad}
        response = requests.post(thingspeak_url, params=payload)
        
        if response.status_code == 200:
            print(f'Edad de la vaca {nombre} ({uid}) enviada correctamente a ThingSpeak.')
        else:
            print(f'Error al enviar la edad de la vaca a ThingSpeak. Código de estado: {response.status_code}')
            print('Contenido de la respuesta:', response.content)
    
    except Exception as e:
        print(f'Error en la solicitud HTTP: {e}')

# Función para actualizar datos de una vaca en la base de datos
def cambiar_datos(uid):
    conn = sqlite3.connect(db_name)
    c = conn.cursor()
    try:
        c.execute("SELECT * FROM vacas WHERE uid = ?", (uid,))
        row = c.fetchone()
        if row:
            print(f"La vaca con UID {uid} ya ha sido registrada anteriormente.")
            respuesta = input('¿Desea actualizar los datos de esta vaca? (S/N): ').lower()
            if respuesta == 's':
                nombre = input(f'Introduce el nuevo nombre para la vaca con UID {uid}: ')
                edad = int(input(f'Introduce la nueva edad para la vaca con UID {uid}: '))
                peso = float(input(f'Introduce el nuevo peso para la vaca con UID {uid} (kg): '))
                id_ternera = int(input(f'Introduce el ID de ternera para la vaca con UID {uid}: '))
                c.execute("UPDATE vacas SET nombre = ?, edad = ?, peso = ? WHERE uid = ?",
                          (nombre, edad, peso, uid))
                conn.commit()
                print(f'Datos para la vaca con UID {uid} actualizados correctamente.')
            else:
                print(f'Datos de la vaca con UID {uid}:')
                print(f'Nombre: {row[1]}, Edad: {row[2]}, Peso: {row[3]}, ID Ternera: {row[4]}')
        else:
            print(f'Vaca detectada con UID: {uid} y datos no asociados')
            respuesta = input('¿Desea asignar datos a esta vaca? (S/N): ').lower()
            if respuesta == 's':
                nombre = input(f'Introduce el nombre para la vaca con UID {uid}: ')
                edad = int(input(f'Introduce la edad en dias para la vaca con UID {uid}: '))
                peso = float(input(f'Introduce el peso para la vaca con UID {uid} (kg): '))
                id_ternera = int(input(f'Introduce el ID de ternera para la vaca con UID {uid}: '))
                guardar_datos(uid, nombre, edad, peso, id_ternera)
            else:
                respuesta = input('¿Desea introducir un nuevo tag? (S/N): ').lower()
                if respuesta != 's':
                    exit()
    except sqlite3.Error as e:
        print("Error al cambiar los datos:", e)
    finally:
        conn.close()

# Código principal
if __name__ == '__main__':
    crear_tabla_vacas()  # Crear la tabla 'vacas' si no existe
    print('En espera de una tarjeta RFID...')
    
    try:
        while True:
            uid = leer_tag()  # Detectar una tarjeta RFID y obtener su UID
            if uid:
                cambiar_datos(uid)  # Gestionar los datos de la vaca según el UID
    except KeyboardInterrupt:
        print('Proceso interrumpido.')
        GPIO.cleanup()
import RPi.GPIO as GPIO
import sqlite3
import time
import requests

SENSOR_PIN = 26
GPIO.setmode(GPIO.BCM)
GPIO.setup(SENSOR_PIN, GPIO.IN)

conn = sqlite3.connect('mediciones.db')
c = conn.cursor()

c.execute('''CREATE TABLE IF NOT EXISTS mediciones
             (id INTEGER PRIMARY KEY, volumen REAL, tiempo TEXT)''')

FACTOR_CONVERSION = 0.00225
VOLUMEN_DESEADO = 0.5

# Configuración de ThingSpeak
thingspeak_api_key = 'TU_API_KEY'
thingspeak_url = f'https://api.thingspeak.com/update?api_key={thingspeak_api_key}'

def medir_volumen(pin, volumen_deseado):
    contador = 0
    volumen_acumulado = 0
    volumen_alcanzado = False

    def contar_pulsos(pin):
        nonlocal contador
        contador += 1

    GPIO.add_event_detect(pin, GPIO.FALLING, callback=contar_pulsos)

    try:
        while not volumen_alcanzado:
            volumen_acumulado = contador * FACTOR_CONVERSION 
            tiempo_actual = time.strftime('%Y-%m-%d %H:%M:%S')
            c.execute("INSERT INTO mediciones (volumen, tiempo) VALUES (?, ?)", (volumen_acumulado, tiempo_actual))
            conn.commit()
            print("Volumen acumulado:", volumen_acumulado, "litros")

            # Enviar datos a ThingSpeak
            payload = {'field1': volumen_acumulado}
            response = requests.post(thingspeak_url, params=payload)
            if response.status_code == 200:
                print("Datos enviados a ThingSpeak.")

            if volumen_acumulado >= volumen_deseado:
                volumen_alcanzado = True  # Marcar que se alcanzó el volumen deseado

            time.sleep(0.1)  # Pausa de 0.1 segundos entre cada medición

    except KeyboardInterrupt:
        GPIO.remove_event_detect(pin)
        GPIO.cleanup()

    return volumen_acumulado

if __name__ == "__main__":
    resultado = medir_volumen(SENSOR_PIN, VOLUMEN_DESEADO)
    print("Volumen deseado alcanzado. Resultado:", resultado)

    # Imprimir el mensaje cada 5 segundos después de alcanzar el volumen deseado
    while True:
        print("¡Volumen deseado alcanzado!")
        time.sleep(10)  # Esperar 10 segundos antes de volver a imprimir el mensaje
